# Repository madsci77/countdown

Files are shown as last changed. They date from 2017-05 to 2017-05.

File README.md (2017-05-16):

This project is a multi-year Burning Man countdown.  When properly set, it will count
down the number of days until the man burns, and on the final day will switch to a
dancing animation.  The next day, the count resets and it begins counting down for
the next year.

Current draw is approximately 2 uA to 5 uA depending on the number of segments active.
Battery life on one CR2032 cell is about 5 years.

| Part | Description | Price (qty 1) | Price (qty 10) |
|---|---|---|---|
| U1	 | Freescale MC9S08LL16CLH	| $2.95 |	$2.77 |
| LCD	 | Varionics VI-321-DP-RC-S	| $4.40	 | $3.28 |
| XTAL | CM51932768DZFT			| $1.20	 | $0.46 |
| BATT | Panasonic CR-2032L/F1N	| $1.10	 | $1.00 |
| C1-C6 | 0.1uF 0603 MLCC | | |

Programming is via a TC2030 programming header with a non-standard pinout.  Sorry -
I only designed this for my own use and went with what I had available.

To set the starting time, you need to make sure that the interval[] array starts
with the current year's interval.  As provided, the code starts with 2013-2014.
You'll also need to set START_DAYS and START_MINS.

The code is fairly simple, but no great effort has been made to clean it up.
tod_ISD() runs once every minute and the current time is recorded in two places
in RAM.  If the MCU is rebooted (due to an SEU caused by a cosmic ray, for example)
counting will resume with the last recorded time if the backup copies are valid.

When the number of days remaining changes, the main loop updates the LCD pins
and shuts down until the next TOD interrupt.

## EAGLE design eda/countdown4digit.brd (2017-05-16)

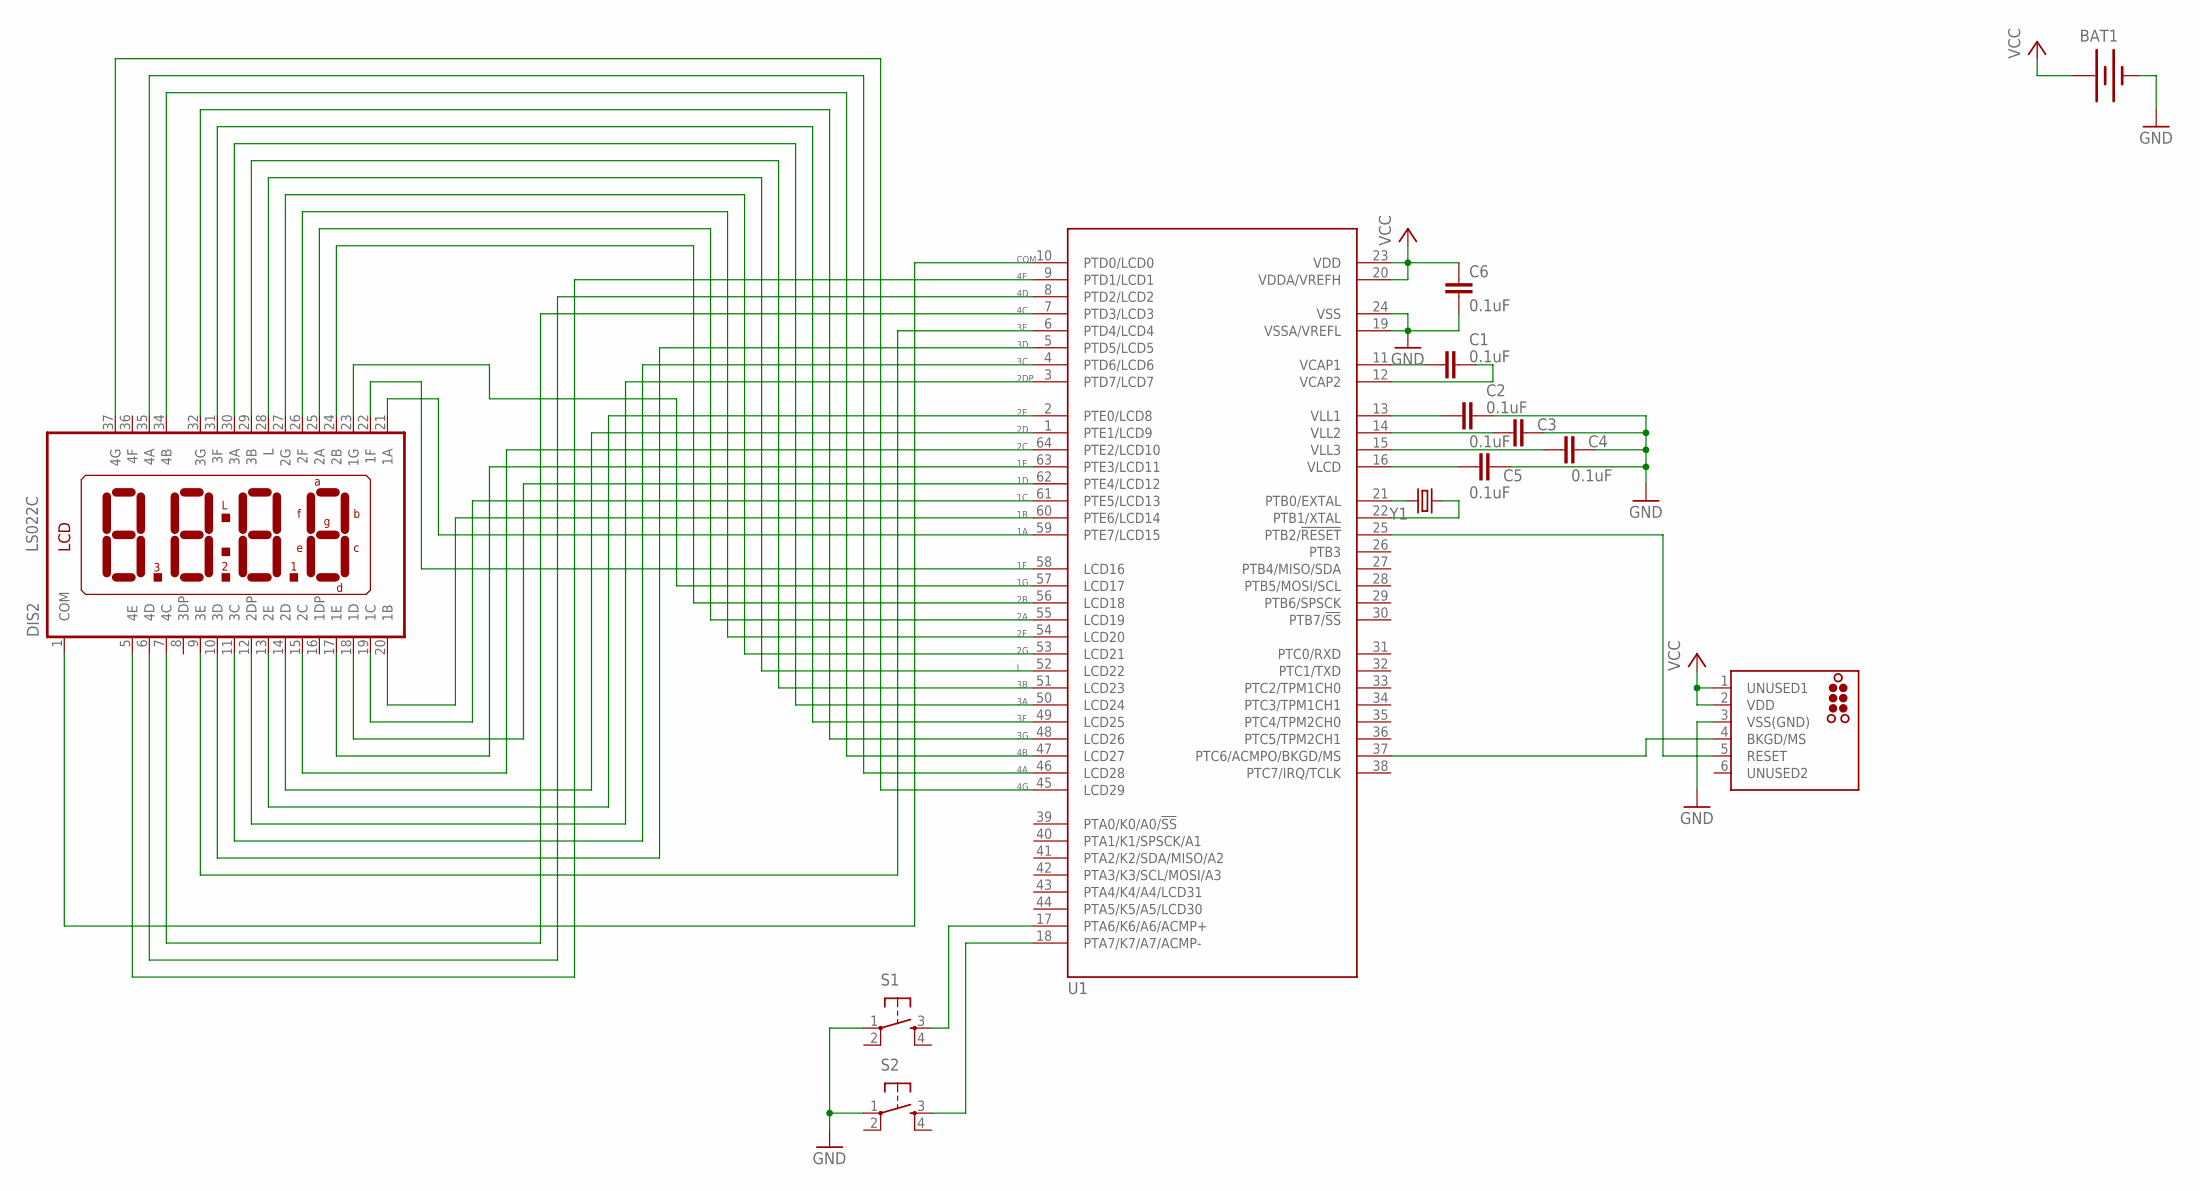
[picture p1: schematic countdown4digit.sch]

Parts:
BAT1: BATTERY12MM; BATTCON_12MM
BDM: TC2030-MCP-NL
C1, C2, C3, C4, C5, C6: 0.1uF; C0603K
DIS2: LS022C
S1, S2: TAC_SWITCHSMD; TACTILE_SWITCH_SMD
U1: MC9S08LL16; LQFP64
Y1: CRYSTALTC26H; TC26H

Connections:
1A: DIS2.21 (1A), U1.59 (PTE7/LCD15)
1B: DIS2.20 (1B), U1.60 (PTE6/LCD14)
1C: DIS2.19 (1C), U1.61 (PTE5/LCD13)
1D: DIS2.18 (1D), U1.62 (PTE4/LCD12)
1E: DIS2.17 (1E), U1.63 (PTE3/LCD11)
1F: DIS2.22 (1F), U1.58 (LCD16)
1G: DIS2.23 (1G), U1.57 (LCD17)
2A: DIS2.25 (2A), U1.55 (LCD19)
2B: DIS2.24 (2B), U1.56 (LCD18)
2C: DIS2.15 (2C), U1.64 (PTE2/LCD10)
2D: DIS2.14 (2D), U1.1 (PTE1/LCD9)
2DP: DIS2.12 (2DP), U1.3 (PTD7/LCD7)
2E: DIS2.13 (2E), U1.2 (PTE0/LCD8)
2F: DIS2.26 (2F), U1.54 (LCD20)
2G: DIS2.27 (2G), U1.53 (LCD21)
3A: DIS2.30 (3A), U1.50 (LCD24)
3B: DIS2.29 (3B), U1.51 (LCD23)
3C: DIS2.11 (3C), U1.4 (PTD6/LCD6)
3D: DIS2.10 (3D), U1.5 (PTD5/LCD5)
3E: DIS2.9 (3E), U1.6 (PTD4/LCD4)
3F: DIS2.31 (3F), U1.49 (LCD25)
3G: DIS2.32 (3G), U1.48 (LCD26)
4A: DIS2.35 (4A), U1.46 (LCD28)
4B: DIS2.34 (4B), U1.47 (LCD27)
4C: DIS2.7 (4C), U1.7 (PTD3/LCD3)
4D: DIS2.6 (4D), U1.8 (PTD2/LCD2)
4E: DIS2.5 (4E), U1.9 (PTD1/LCD1)
4G: DIS2.37 (4G), U1.45 (LCD29)
COM: DIS2.1 (COM), U1.10 (PTD0/LCD0)
GND: BAT1.GND (-), BDM.3 (VSS(GND)), C2.1, C3.1, C4.1, C5.1, C6.2, S1.1, S2.1, U1.19 (VSSA/VREFL), U1.24 (VSS)
L: DIS2.28 (L), U1.52 (LCD22)
unnamed: C1.2, U1.11 (VCAP1)
unnamed: C1.1, U1.12 (VCAP2)
unnamed: C2.2, U1.13 (VLL1)
unnamed: C3.2, U1.14 (VLL2)
unnamed: C4.2, U1.15 (VLL3)
unnamed: C5.2, U1.16 (VLCD)
unnamed: U1.21 (PTB0/EXTAL), Y1.2
unnamed: U1.22 (PTB1/XTAL), Y1.1
unnamed: BDM.4 (BKGD/MS), U1.37 (PTC6/ACMPO/BKGD/MS)
unnamed: BDM.5 (RESET), U1.25 (PTB2/!RESET)
unnamed: S1.3, U1.17 (PTA6/K6/A6/ACMP+)
unnamed: S2.3, U1.18 (PTA7/K7/A7/ACMP-)
VCC: BAT1.PWR@1 (+), BDM.1 (UNUSED1), BDM.2 (VDD), C6.1, U1.20 (VDDA/VREFH), U1.23 (VDD)

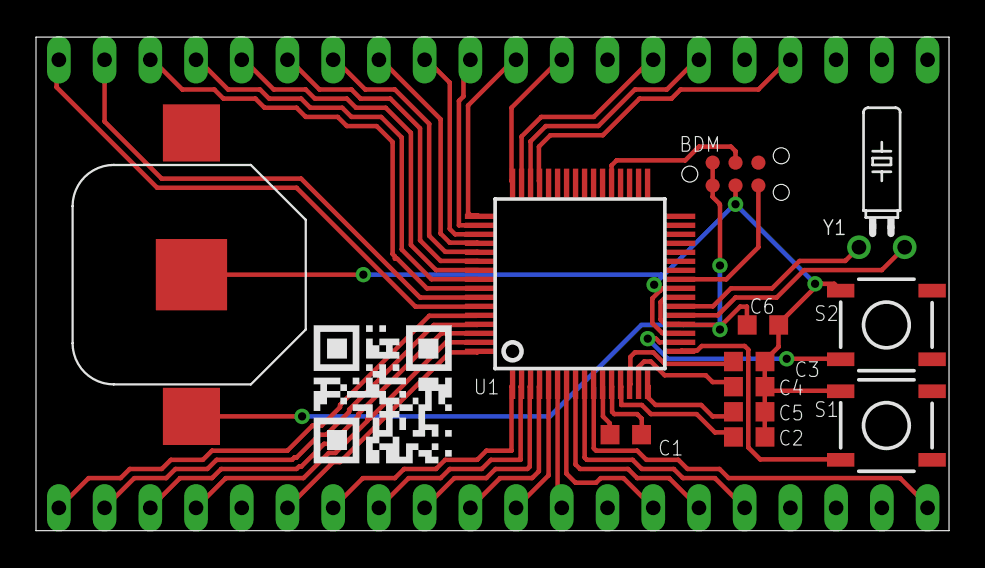
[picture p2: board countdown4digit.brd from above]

Board: 2 copper layers, 50.7 x 27.4 mm, 14 parts (1 on the bottom side), 44 nets.

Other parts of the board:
U$1: QR-CODE-L-MED

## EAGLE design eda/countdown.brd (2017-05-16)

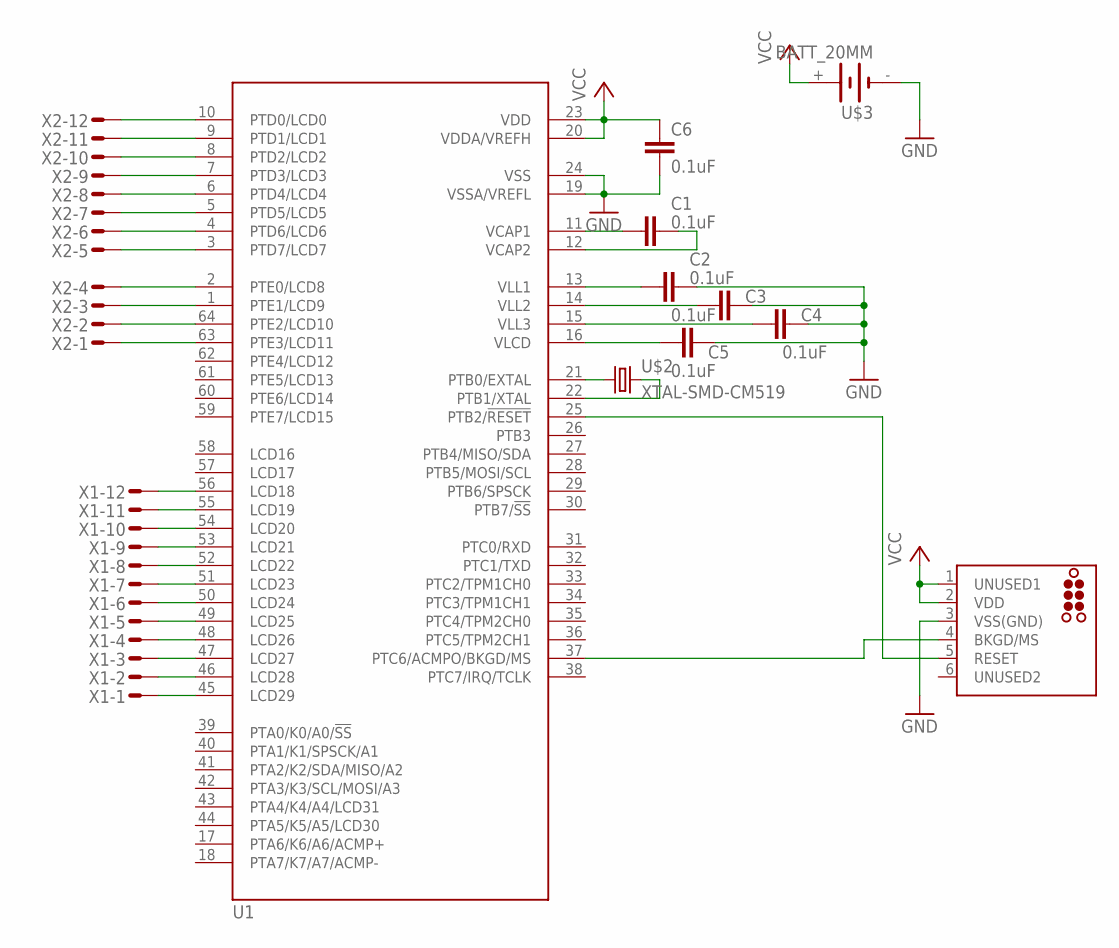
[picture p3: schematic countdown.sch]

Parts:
BDM: TC2030-MCP-NL
C1, C2, C3, C4, C5, C6: 0.1uF; C0603K
U1: MC9S08LL16; LQFP64
U$2: XTAL-SMD-CM519; SMD-XTAL-CM519
U$3: BATT_20MM
X1-, X2-: HEADER-12-EDGE

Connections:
GND: BDM.3 (VSS(GND)), C2.1, C3.1, C4.1, C5.1, C6.2, U1.19 (VSSA/VREFL), U1.24 (VSS), U$3.-
unnamed: U1.63 (PTE3/LCD11), X2-.1
unnamed: U1.64 (PTE2/LCD10), X2-.2
unnamed: U1.1 (PTE1/LCD9), X2-.3
unnamed: U1.2 (PTE0/LCD8), X2-.4
unnamed: U1.3 (PTD7/LCD7), X2-.5
unnamed: U1.4 (PTD6/LCD6), X2-.6
unnamed: U1.5 (PTD5/LCD5), X2-.7
unnamed: U1.6 (PTD4/LCD4), X2-.8
unnamed: U1.7 (PTD3/LCD3), X2-.9
unnamed: U1.8 (PTD2/LCD2), X2-.10
unnamed: U1.9 (PTD1/LCD1), X2-.11
unnamed: U1.10 (PTD0/LCD0), X2-.12
unnamed: U1.45 (LCD29), X1-.1
unnamed: U1.46 (LCD28), X1-.2
unnamed: U1.47 (LCD27), X1-.3
unnamed: U1.48 (LCD26), X1-.4
unnamed: U1.49 (LCD25), X1-.5
unnamed: U1.50 (LCD24), X1-.6
unnamed: U1.51 (LCD23), X1-.7
unnamed: U1.52 (LCD22), X1-.8
unnamed: U1.53 (LCD21), X1-.9
unnamed: U1.54 (LCD20), X1-.10
unnamed: U1.55 (LCD19), X1-.11
unnamed: U1.56 (LCD18), X1-.12
unnamed: C1.2, U1.11 (VCAP1)
unnamed: C1.1, U1.12 (VCAP2)
unnamed: C2.2, U1.13 (VLL1)
unnamed: C3.2, U1.14 (VLL2)
unnamed: C4.2, U1.15 (VLL3)
unnamed: C5.2, U1.16 (VLCD)
unnamed: U1.21 (PTB0/EXTAL), U$2.P$1 (1)
unnamed: U1.22 (PTB1/XTAL), U$2.P$2 (2)
unnamed: BDM.4 (BKGD/MS), U1.37 (PTC6/ACMPO/BKGD/MS)
unnamed: BDM.5 (RESET), U1.25 (PTB2/!RESET)
VCC: BDM.1 (UNUSED1), BDM.2 (VDD), C6.1, U1.20 (VDDA/VREFH), U1.23 (VDD), U$3.+

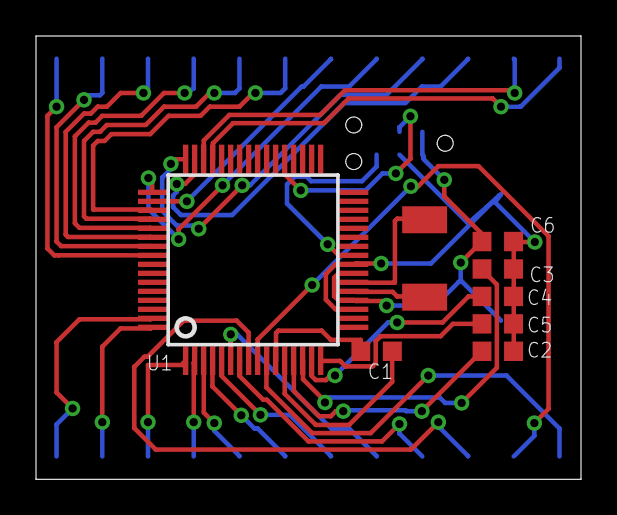
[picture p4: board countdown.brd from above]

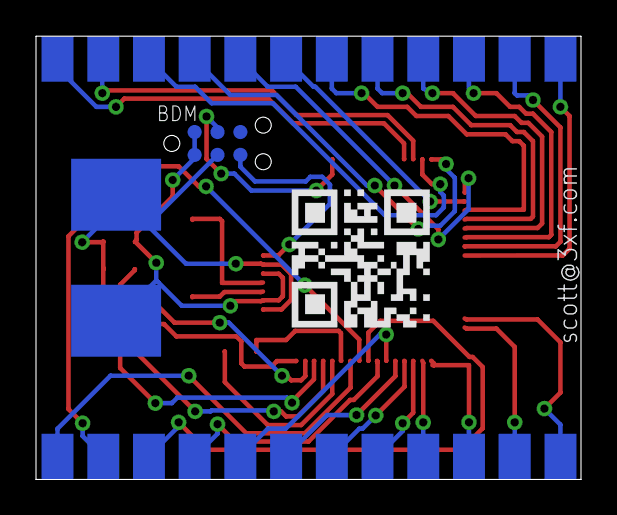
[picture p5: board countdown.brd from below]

Board: 2 copper layers, 30.3 x 24.6 mm, 13 parts (3 on the bottom side), 36 nets.

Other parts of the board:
U$1: QR-CODE-L-MED

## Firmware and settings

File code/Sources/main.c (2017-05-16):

#include <hidef.h>
#include "derivative.h"
#include <string.h>
#include "lcd.h"

/*

Yearly countdown timer
MC9S08LL16

To set:

Make sure interval starts with number of days between the upcoming burn and the next year's burn.
Set START_DAYS to number of full days before the burn, and START_MINS to the time from programming
until midnight.

*/

const unsigned short interval[] = {	364,	// 2016-2017
												364,	// 2017-2018
												364,	// 2018-2019
												371,	// 2019-2020
												364, 364, 364, 364, 364, 371, 364, 364, 364, 364, 364, 371, 364, 364, 364, 364, 371, 363, 364, 364, 364, 364, 371};

#define AsmStop  __asm STOP;  
#define AsmNop   __asm NOP;

volatile unsigned char state = 1;

// Starting conditions - to be replaced with external configuration input signal

#define START_DAYS 11
#define START_MINS 900

// Not zeroed out, so retained across resets (RFI, SEUs)
volatile unsigned short days @ 0x870; 				// Days in count (0 = target date)
volatile unsigned short mins @ 0x872;				// Minutes left in this day
volatile unsigned short year @ 0x874;				// Year index, starting with 2013
volatile unsigned short safety_sig @ 0x860;		// Signature indicating RAM previously initialized
volatile unsigned short safety_days @ 0x862;		// 1s complement of counters for data validity checking
volatile unsigned short safety_year @ 0x864;
volatile unsigned short safety_mins @ 0x866;



// ********* System Initialization **********

void SystemInit(void)
{

  	// Set up internal clock source (32.768 kHz crystal)
  
	ICSC2 = 0x0f;			// Low power, oscillator requested, ICSERCLK enabled, enabled in stop
	ICSC1 = 0x80;			// External reference, FLL bypassed external

	SOPT1 = 0x60;			// COP disabled, STOP enabled
//	SOPT1 = 0x63;			// Enable BDM and RST pins for testing
	SPMSC1 = 0x00;			// LVD disabled

	IRQSC_IRQPE = 0;		// IRQ pin disabled

	// Set up time-of-day clock
	
	TODC_TODCLKS = 0;		// Clock source
	TODC_TODPS = 1;		// Prescaler
	TODSC_MTCHIE = 1;		// Match interrupt enabled
	TODSC_MTCHEN = 1;		// Match enabled
	TODSC_SECIE = 0;		// No second interrupt
	TODSC_QSECIE = 0;		// No quarter-second interrupt
	TODM = 60 << 2;	// Match count (every 60 seconds)
//	TODM = 4 << 2;			// Fast clock for testing
	TODC_TODEN =1;			// Enable module
 
	// All I/O pins to output
	PTADD = PTBDD = PTCDD = PTDDD = PTEDD = 0xFF;

	// Set all I/O pins low
	PTAD = PTBD = PTCD = PTDD = PTED = 0x00;

	LCDInit();

	SCGC1 = 0b10001000; 	// TPM2, TPM1, ADC, I2C, and SCI clocks disabled
	SCGC2 = 0b01000110;	// IRQ, KBI, ACMP, and SPI clocks disabled

	SPMSC2 = 0x80;			// LPrun enabled

	EnableInterrupts;
     
}

// ********* Main Loop **********

void main(void) 
{
	int i;
	// If signature and complments match, data is still valid across CPU reset - otherwise load defaults
	if ((safety_sig != 0xabcd) || (days != ~safety_days) || (mins != ~safety_mins) || (year != ~safety_year))
	{
		days = START_DAYS;
		mins = START_MINS;
		year = 0;
	}
	
	SystemInit();

	ClearDisplay();

	for (i = 2550; i; i--) {
		AsmNop;
		AsmNop;
		AsmNop;
	}

	for(;;)	
	{   

		if (state)
		{
			// Only update display on change to avoid extra time doing math
			if (days)
			{
				BlinkOff();
				SetDigit(0, days % 10); 
				if (days >= 10) SetDigit(1, (days % 100) / 10);
				else SetDigit(1, LCD_BLANK);
				if (days >= 100) SetDigit(2, (days / 100) & 0xff);
				else SetDigit(2, LCD_BLANK);
			}
			else
			{
				// Target date - display animation
				SetDigit(0, LCD_ZIGZAG);
				SetDigit(1, LCD_ZIGZAG);
				SetDigit(2, LCD_ZIGZAG);
				BlinkOn();
			}
			state = 0;
		}
		AsmStop;    
	}
}


// ********* Time-of-Day Interrupt **********

interrupt VectorNumber_Vtod void tod_ISR(void)
{
	safety_sig = 0xabcd;
	if (mins)
	{
		mins--;
	}
	else
	{
		mins = 1439;
		if (days)
		{
			days--;
		}
		else
		{
			// Done with this year and last-day animation, load next interval
			days = interval[year]-1;
			year++;		
			safety_year = ~year;
		}		
		state = 1;
		safety_days = ~days;
	}
	safety_mins = ~mins;
	// Acknowledge interrupt sources
	TODSC_SECF = 1; 
	TODSC_MTCHF = 1;
	TODSC_QSECF = 1;
}

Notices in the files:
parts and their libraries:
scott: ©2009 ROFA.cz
